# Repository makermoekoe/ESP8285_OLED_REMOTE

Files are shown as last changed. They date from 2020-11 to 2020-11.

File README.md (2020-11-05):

# ESP8285_OLED_REMOTE

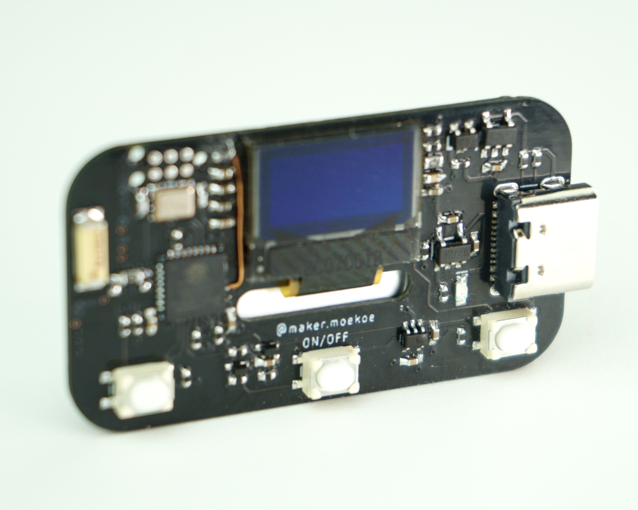
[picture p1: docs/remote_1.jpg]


(Click on the image for a small video.)

Little WiFi remote based on ESP8285 SoC. Furthermore it contains a LiPo protection + charging circuit, a 3.3volts voltage regulator, a 64x48 pixels OLED display and three buttons.
The power latching circuit ensures that the ESP8285 don't need to be in deep sleep mode while in OFF state. This puts it down to around 3µA during 'sleep', due to the battery protection. It can be woke up only by the middle button. The battery protection occupies reverse voltage protection through the mosfet. Overdischarge voltage of the XB5353A is 2.4volts, which is only for safety reasons. The battery voltage should always be checked with the voltage divider, which gives you an estimation of the battery state.

Main components are:
- ESP8285 QFN32 SoC
- 0.49" 64x48 pixels 14pin OLED display
- XB5353A protection
- SE7401U polarity
- MCP73831 charging
- RT9193 regulator
- AN2051 2.4GHz antenna

Check out the code in the 'code' section. It is used in PlatformIO, but can be shifted to Arduino IDE easily. The code is exactly the same.

When you have questions then feel free to ask.

Have fun! :)

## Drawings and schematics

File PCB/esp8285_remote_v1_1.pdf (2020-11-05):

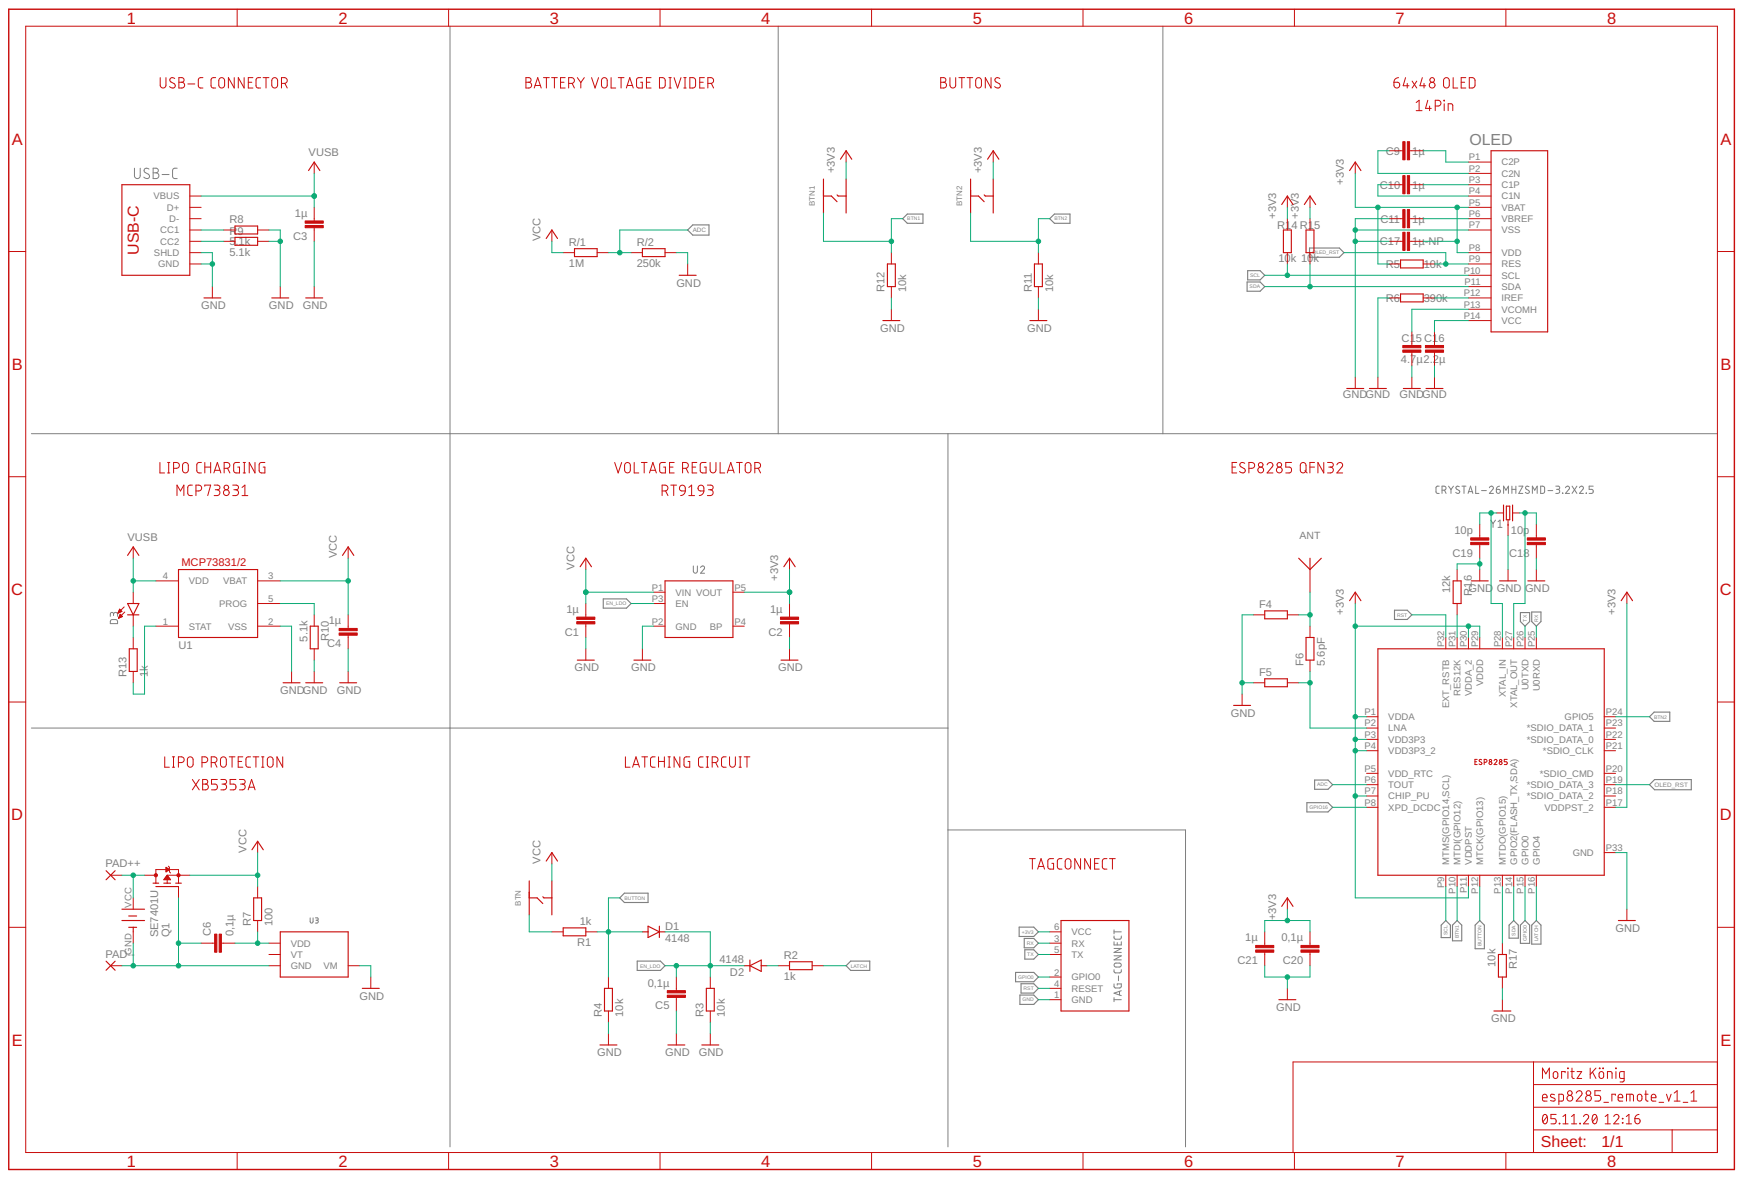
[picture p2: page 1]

+3V3 1µ 1µ 10k GND 1k 1M 250k 1k GND 1µ 1µ 5.1k GND GND GND GND VUSB GND 100 0,1µ 4148 4148 GND 5.1k 5.1k GND GND SE7401U GND0,1µGNDGND 10k GND 10k GND 10k 390k 10k 10k 1µ1µ1µ GNDGND 4.7µ2.2µ GNDGND 1µ-NP +3V3 +3V3 +3V3 12k 10p 10p GND GND 1µ 0,1µ GND +3V3 +3V3 +3V GND 3 GND 10k GND GND 5.6pF +3V3 10k GND +3V3 1k VUSB VCC VCC VCCVCC VCC C1 C2 R3 R2 R/1 R/2 R1 C3 C4R10 R7 C6D1 D2 R8 R9 VCC 6 RX 3 TX 5 GPIO0 2 RESET 4 GND 1 CC1D- D+ VBUS CC2 SHLD GND VDD VTGND VM Q1 C5 STAT 1 VSS 2 VBAT 3 VDD 4 PROG 5 U1 R4 VIN P1 EN P3 GND P2 VOUT P5 BP P4 R12 BTN BTN1 VSS P7 VBREF P6 VBAT P5 C1N P4 C1P P3 C2N P2 C2P P1 VDD P8 RES P9 SCL P10 SDA P11 IREF P12 VCOMH P13 VCC P14OLED R5 R6 R14 R15 C9 C10 C11C15 C16 C17 MTMS(GPIO14,SCL) P9 XPD_DCDC P8 CHIP_PU P7 TOUT P6 VDD_RTC P5 VDD3P3_2 P4 VDD3P3 P3 LNA P2 VDDA P1 MTDI(GPIO12) P10 VDDPST P11 MTCK(GPIO13) P12 MTDO(GPIO15) P13 GPIO2(FLASH_TX,SDA) P14 GPIO0 P15 GPIO4 P16 EXT_RSTB P32 RES12K P31 VDDA_2 P30 VDDD P29 XTAL_IN P28 XTAL_OUT P27 U0TXD P26 U0RXD P25 GPIO5 P24 *SDIO_DATA_1 P23 *SDIO_DATA_0 P22 *SDIO_CLK P21 *SDIO_CMD P20 *SDIO_DATA_3 P19 *SDIO_DATA_2 P18 VDDPST_2 P17 GND P33 R16 C19 C18 C21 C20ANT R17 F4F5 F6 R11 BTN2 R13 VCC GND PAD++ PAD-- GND +3V3 BUTTON BUTTON RX RX TX TX ADC ADC GPIO0 GPIO0 RST RST EN_LDO EN_LDO LATCH LATCH SCL SCL SDA SDA OLED_RST OLED_RST GPIO16 BTN1 BTN1 BTN2 BTN2 USB-C MCP73831/2 Sheet: ABCDE 1 2 3 4 5 6 7 8 ABCDE 1 2 3 4 5 6 7 81/1

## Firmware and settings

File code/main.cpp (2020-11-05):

#include <Arduino.h>
#include <U8g2lib.h>
#include <Wire.h>
#include <NTPClient.h>
#include <ESP8266WiFi.h>
#include <WiFiUdp.h>

#define OLED_RST 10 //U8X8_PIN_NONE
U8G2_SSD1306_64X32_1F_F_HW_I2C u8g2(U8G2_R0, /* reset=*/ OLED_RST);


const char* ssid = "XX";
const char* password = "XX";

WiFiServer server(1023);

WiFiUDP ntpUDP;
NTPClient timeClient(ntpUDP);

const int button_on = 13;
const int button_left = 12;
const int button_right = 5;
const int latch = 4;

int counter = 0;


int X(int textgroesse, int textwidth, int n) {
  //gibt die X koordinate aus, damit text mit n zeichen mittig ist
  return (0.5 * (64 - textgroesse * (textwidth * n - 1)));
}//end int X

int Y(int textgroesse, int textheight, float f) {
  //gibt die Y koordinate aus, damit text mittig ist
  return (f * 48 + (textgroesse * textheight/2));
}//end int Y

void setup() {
  pinMode(latch, OUTPUT);
  digitalWrite(latch, HIGH);

  Wire.begin(2, 14);
  Serial.begin(115200);
  Serial.println("start");

  pinMode(OLED_RST, OUTPUT);
  pinMode(button_on, INPUT);
  pinMode(button_left, INPUT);
  pinMode(button_right, INPUT);

  u8g2.begin();
  u8g2.clearBuffer();

  u8g2.clearBuffer();
  u8g2.setFont(u8g2_font_inb16_mf);
  u8g2.setCursor(X(1,14,3), Y(1,16,0.5));
  u8g2.print("HEY");
  u8g2.sendBuffer();

  WiFi.mode(WIFI_STA);
  WiFi.begin(ssid, password);

  int stat = 0;
  while ((WiFi.status() != WL_CONNECTED)) {
    
    /*for(int i=0; i<3; i++){
      u8g2.clearBuffer();
      u8g2.setFont(u8g2_font_inb16_mf);
      u8g2.setCursor(X(1,14,1), Y(1,16,0.5));
      if(stat == 0) u8g2.print("H");
      else if(stat == 1) u8g2.print("E");
      else if(stat == 2) u8g2.print("Y");
      stat++;
      if(stat > 2) stat = 0;
      u8g2.sendBuffer();
      delay(300);
    }*/
    delay(100);
  }

  timeClient.begin();
  timeClient.setTimeOffset(3600);
}

unsigned long t_time = millis();

void loop() {
  //Serial.println(("Button 1: " + String(digitalRead(button_left)) + ", Button 2: " + String(digitalRead(button_on)) + ", Button 3: " + String(digitalRead(button_right))));


  timeClient.update();
  if(millis() >= t_time + 100){
    String ntp = timeClient.getFormattedTime();
    u8g2.clearBuffer();          // clear the internal memory
    u8g2.setFont(u8g2_font_6x12_tn );  // choose a suitable font
    u8g2.setCursor(X(1,6,8), Y(1,12,0.3));
    u8g2.print(ntp);

    String c = String(counter);
    int len = c.length();
    u8g2.setCursor(X(1,6,len), Y(1,12,0.7));
    u8g2.print(c);
    u8g2.sendBuffer();
    t_time = millis();
  }
  

  if(digitalRead(button_right) == 1){
    if(counter < 10) counter++;
    u8g2.clearBuffer();          // clear the internal memory
    u8g2.setFont(u8g2_font_inb16_mf );  // choose a suitable font
    if(counter < 10) u8g2.setCursor(X(1,14,1), Y(1,16,0.5));
    else u8g2.setCursor(X(1,14,2), Y(1,16,0.5));
    u8g2.print(counter);
    u8g2.sendBuffer();
    while(digitalRead(button_right) == 1) delay(20);
  }
  if(digitalRead(button_left) == 1){
    if(counter > 0) counter--;
    u8g2.clearBuffer();          // clear the internal memory
    u8g2.setFont(u8g2_font_inb16_mf );  // choose a suitable font
    if(counter < 10) u8g2.setCursor(X(1,14,1), Y(1,16,0.5));
    else u8g2.setCursor(X(1,14,2), Y(1,16,0.5));
    u8g2.print(counter);
    u8g2.sendBuffer();
    while(digitalRead(button_left) == 1) delay(20);
  }

  if(digitalRead(button_on) == 1){
    u8g2.clearBuffer();          // clear the internal memory
    u8g2.setFont(u8g2_font_inb16_mf );  // choose a suitable font
    u8g2.setCursor(X(1,14,3), Y(1,16,0.5));
    u8g2.print("BYE");
    u8g2.sendBuffer();

    delay(2000);
    digitalWrite(latch, LOW);
    delay(1000);
  }


}

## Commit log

2020-11-05 initial release
    [copper_bottom_l4.gbr, copper_inner_l2.gbr, copper_inner_l3.gbr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]
2020-11-05 Update esp8285_remote_v1_1.pdf
    corrected charging LED orientation
